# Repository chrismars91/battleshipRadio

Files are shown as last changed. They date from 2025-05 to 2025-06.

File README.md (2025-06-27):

https://www.instructables.com/BattLedRadio-the-LED-Radio-Battleship-SAMD21-Editi/


*** New board gerber below with better JTAG programming pads and a battery powered option. Updated BOM in the link. ***
https://www.pcbway.com/project/shareproject/rfm69_battleship_battery_7544f334.html

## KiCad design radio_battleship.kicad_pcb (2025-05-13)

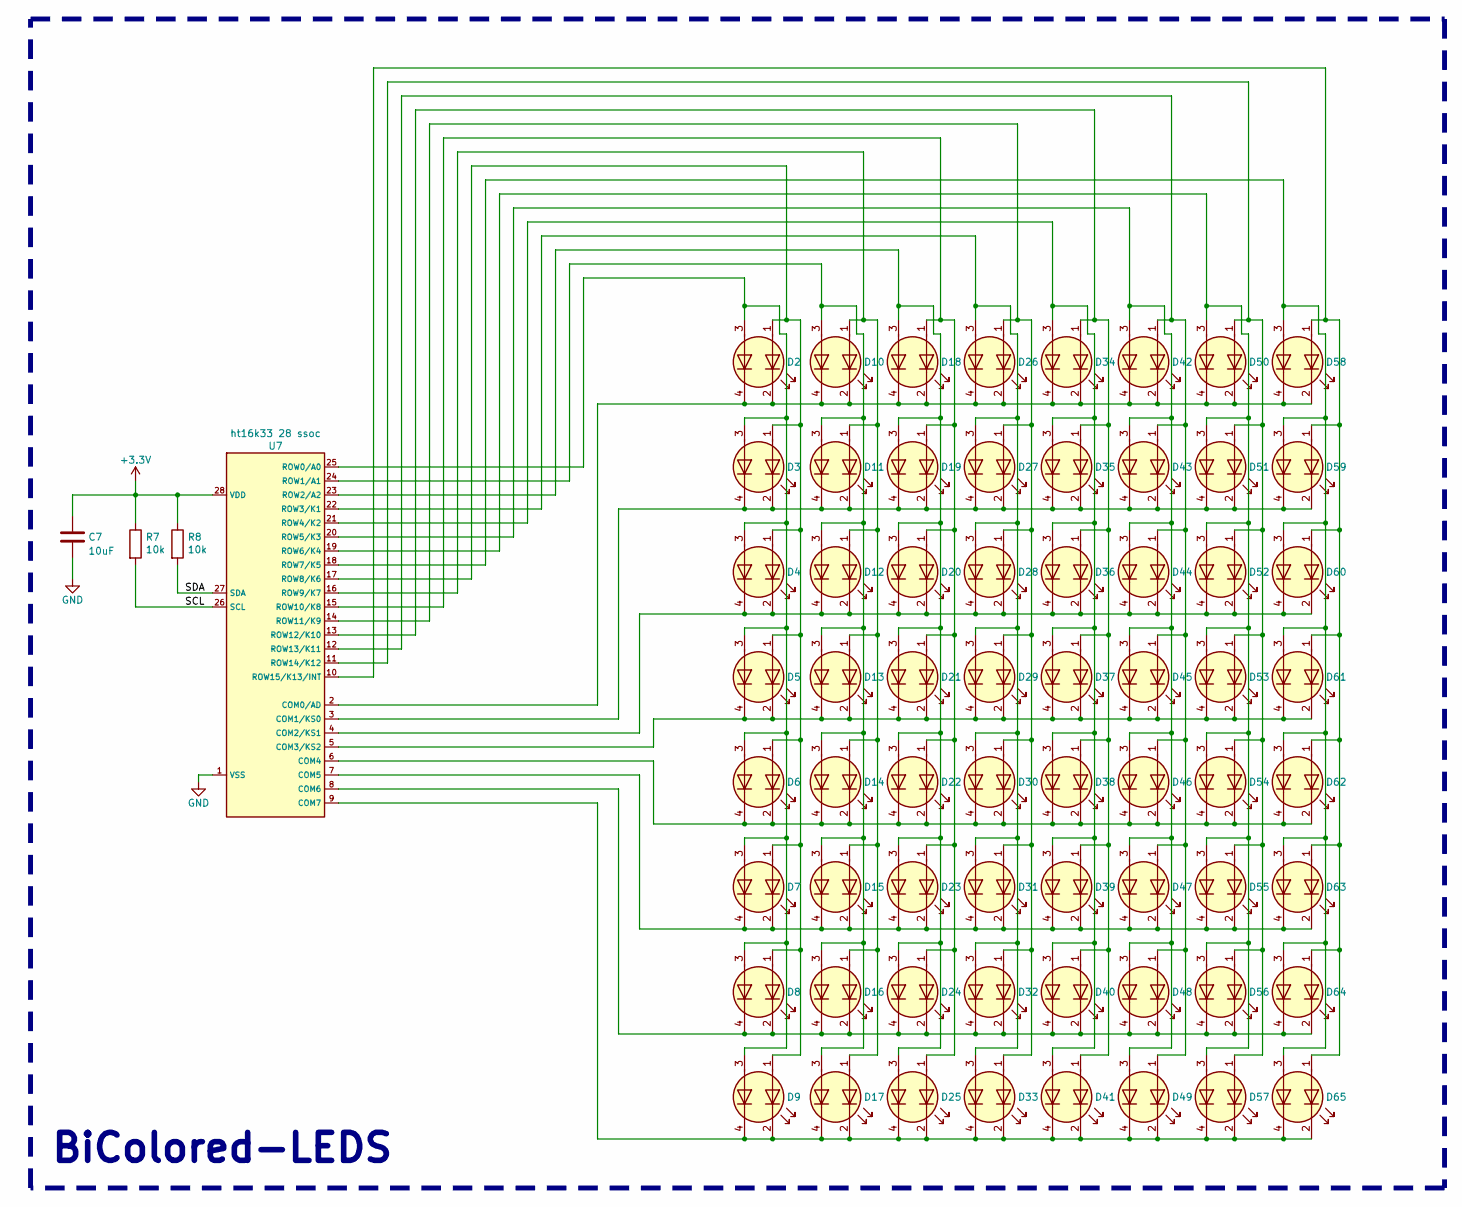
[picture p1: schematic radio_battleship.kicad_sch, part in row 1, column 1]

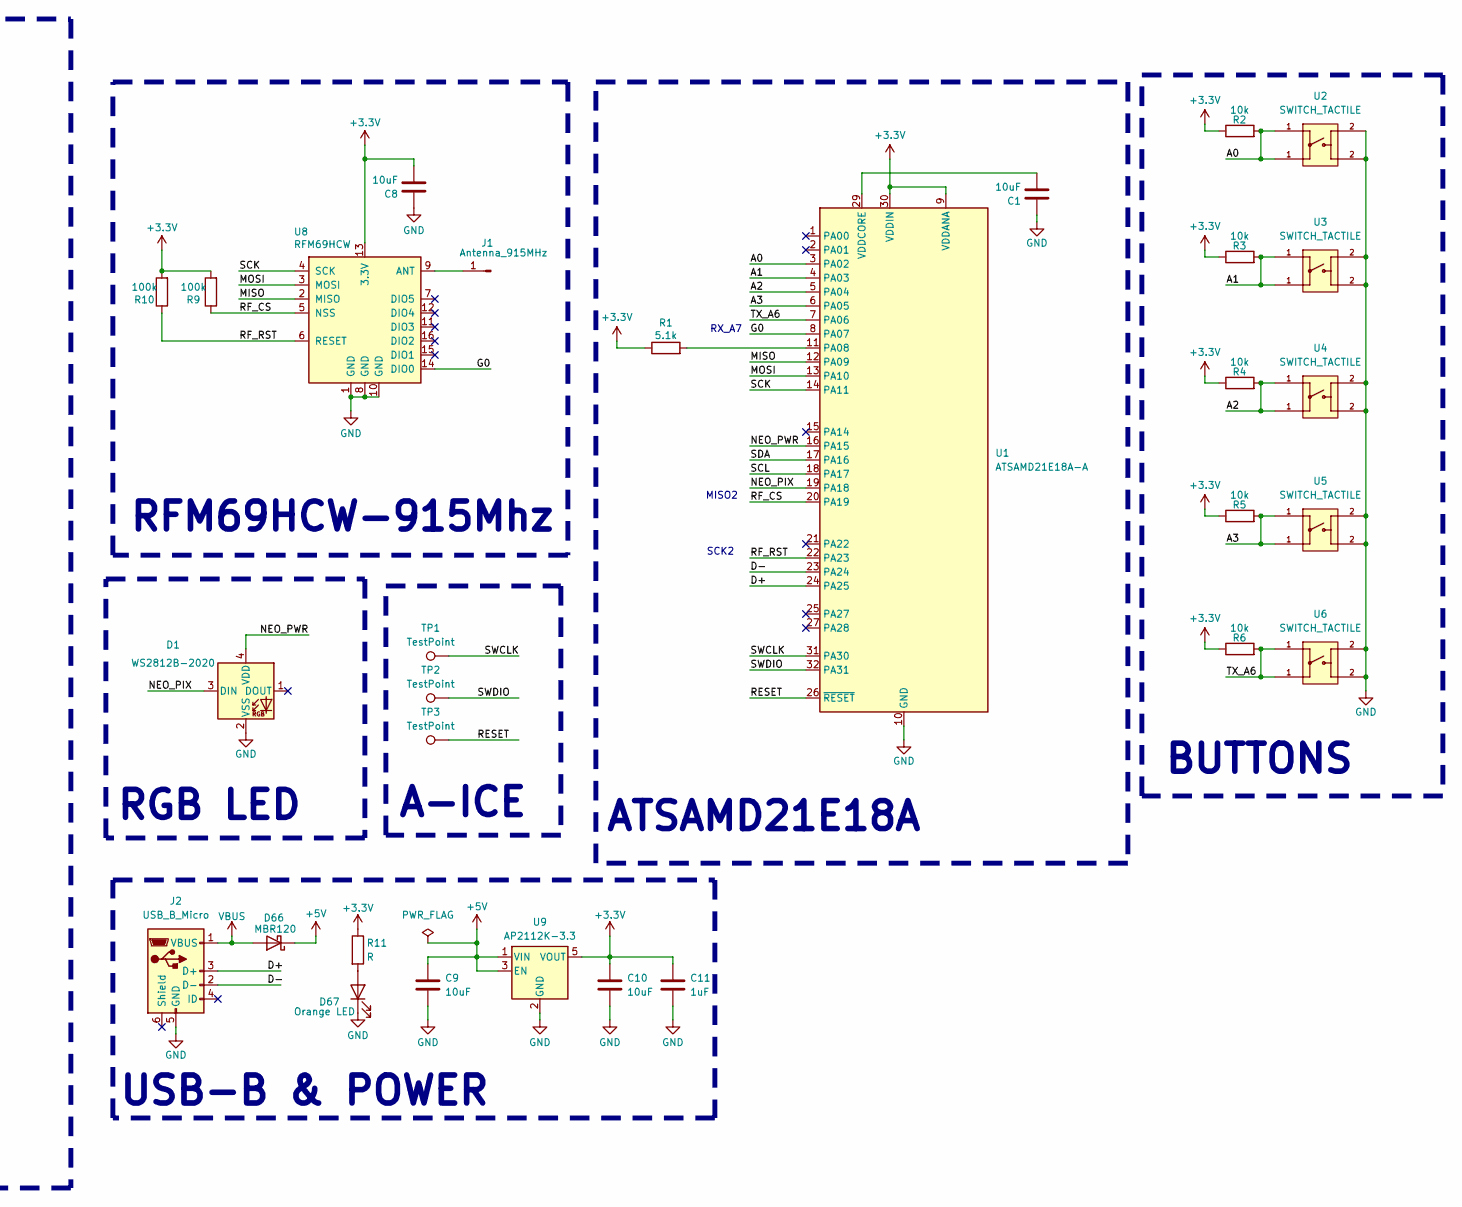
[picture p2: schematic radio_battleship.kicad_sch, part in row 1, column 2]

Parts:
C1, C7, C8, C9, C10: 10uF; C_0603_1608Metric
C11: 1uF; C_0603_1608Metric
D1: WS2812B-2020; custom_ws28_2m_led
D2, D3, D4, D5, D6, D7, D8, D9, D10, D11, D12, D13, D14, D15, D16, D17, D18, D19, D20, D21, D22, D23, D24, D25, D26, D27, D28, D29, D30, D31, D32, D33, D34, D35, D36, D37, D38, D39, D40, D41, D42, D43, D44, D45, D46, D47, D48, D49, D50, D51, D52, D53, D54, D55, D56, D57, D58, D59, D60, D61, D62, D63, D64, D65: LTST-BILED-15X16
D66: MBR120; D_SOD-123F
D67: Orange LED; LED_0805_2012Metric
J1: Antenna_915MHz; ant
J2: USB_B_Micro; USB_Micro-B_Wuerth_629105150521
R1: 5.1k; R_0603_1608Metric
R2, R3, R4, R5, R6, R7, R8: 10k; R_0603_1608Metric
R9, R10: 100k; R_0603_1608Metric
R11: R; R_0603_1608Metric
TP1, TP2, TP3: TestPoint; TestPoint_Pad_2.5x2.5mm
U1: ATSAMD21E18A-A; TQFP-32_7x7mm_P0.8mm
U2, U3, U4, U5, U6: SWITCH_TACTILE
U7: ht16k33 28 ssoc; HT16K33_ssop
U8: RFM69HCW
U9: AP2112K-3.3; SOT-23-5

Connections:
+3.3V: C7.1, C8.2, C10.1, C11.1, R1.1, R2.1, R3.1, R4.1, R5.1, R6.1, R7.1, R8.1, R9.2, R10.2, R11.1, U1.9 (VDDANA), U1.30 (VDDIN), U7.28 (VDD), U8.13 (3.3V), U9.5 (VOUT)
+5V: C9.1, D66.1 (K), U9.1 (VIN), U9.3 (EN)
/A0: R2.2, U1.3 (PA02), U2.1
/A1: R3.2, U1.4 (PA03), U3.1
/A2: R4.2, U1.5 (PA04), U4.1
/A3: R5.2, U1.6 (PA05), U5.1
/D+: J2.3 (D+), U1.24 (PA25)
/D-: J2.2 (D-), U1.23 (PA24)
/G0: U1.8 (PA07), U8.14 (DIO0)
/MISO: U1.12 (PA09), U8.2 (MISO)
/MOSI: U1.13 (PA10), U8.3 (MOSI)
/NEO_PIX: D1.3 (DIN), U1.19 (PA18)
/NEO_PWR: D1.4 (VDD), U1.16 (PA15)
/RESET: TP3.1, U1.26 (~RESET)
/RF_CS: R9.1, U1.20 (PA19), U8.5 (NSS)
/RF_RST: R10.1, U1.22 (PA23), U8.6 (RESET)
/SCK: U1.14 (PA11), U8.4 (SCK)
/SCL: R7.2, U1.18 (PA17), U7.26 (SCL)
/SDA: R8.2, U1.17 (PA16), U7.27 (SDA)
/SWCLK: TP1.1, U1.31 (PA30)
/SWDIO: TP2.1, U1.32 (PA31)
/TX_A6: R6.2, U1.7 (PA06), U6.1
GND: C1.1, C7.2, C8.1, C9.2, C10.2, C11.2, D1.2 (VSS), D67.1 (K), J2.5 (GND), U1.10 (GND), U1.28 (GND), U2.2, U3.2, U4.2, U5.2, U6.2, U7.1 (VSS), U8.1 (GND), U8.8 (GND), U8.10 (GND), U9.2 (GND)
unnamed: D2.1 (A1), D3.1 (A1), D4.1 (A1), D5.1 (A1), D6.1 (A1), D7.1 (A1), D8.1 (A1), D9.1 (A1), U7.17 (ROW8/K6)
unnamed: D2.3 (A2), D3.3 (A2), D4.3 (A2), D5.3 (A2), D6.3 (A2), D7.3 (A2), D8.3 (A2), D9.3 (A2), U7.25 (ROW0/A0)
unnamed: D10.1 (A1), D11.1 (A1), D12.1 (A1), D13.1 (A1), D14.1 (A1), D15.1 (A1), D16.1 (A1), D17.1 (A1), U7.16 (ROW9/K7)
unnamed: D10.3 (A2), D11.3 (A2), D12.3 (A2), D13.3 (A2), D14.3 (A2), D15.3 (A2), D16.3 (A2), D17.3 (A2), U7.24 (ROW1/A1)
unnamed: D2.2 (K1), D2.4 (K2), D10.2 (K1), D10.4 (K2), D18.2 (K1), D18.4 (K2), D26.2 (K1), D26.4 (K2), D34.2 (K1), D34.4 (K2), D42.2 (K1), D42.4 (K2), D50.2 (K1), D50.4 (K2), D58.2 (K1), D58.4 (K2), U7.2 (COM0/AD)
unnamed: D3.2 (K1), D3.4 (K2), D11.2 (K1), D11.4 (K2), D19.2 (K1), D19.4 (K2), D27.2 (K1), D27.4 (K2), D35.2 (K1), D35.4 (K2), D43.2 (K1), D43.4 (K2), D51.2 (K1), D51.4 (K2), D59.2 (K1), D59.4 (K2), U7.3 (COM1/KS0)
unnamed: D4.2 (K1), D4.4 (K2), D12.2 (K1), D12.4 (K2), D20.2 (K1), D20.4 (K2), D28.2 (K1), D28.4 (K2), D36.2 (K1), D36.4 (K2), D44.2 (K1), D44.4 (K2), D52.2 (K1), D52.4 (K2), D60.2 (K1), D60.4 (K2), U7.4 (COM2/KS1)
unnamed: D5.2 (K1), D5.4 (K2), D13.2 (K1), D13.4 (K2), D21.2 (K1), D21.4 (K2), D29.2 (K1), D29.4 (K2), D37.2 (K1), D37.4 (K2), D45.2 (K1), D45.4 (K2), D53.2 (K1), D53.4 (K2), D61.2 (K1), D61.4 (K2), U7.5 (COM3/KS2)
unnamed: D6.2 (K1), D6.4 (K2), D14.2 (K1), D14.4 (K2), D22.2 (K1), D22.4 (K2), D30.2 (K1), D30.4 (K2), D38.2 (K1), D38.4 (K2), D46.2 (K1), D46.4 (K2), D54.2 (K1), D54.4 (K2), D62.2 (K1), D62.4 (K2), U7.6 (COM4)
unnamed: D7.2 (K1), D7.4 (K2), D15.2 (K1), D15.4 (K2), D23.2 (K1), D23.4 (K2), D31.2 (K1), D31.4 (K2), D39.2 (K1), D39.4 (K2), D47.2 (K1), D47.4 (K2), D55.2 (K1), D55.4 (K2), D63.2 (K1), D63.4 (K2), U7.7 (COM5)
unnamed: D8.2 (K1), D8.4 (K2), D16.2 (K1), D16.4 (K2), D24.2 (K1), D24.4 (K2), D32.2 (K1), D32.4 (K2), D40.2 (K1), D40.4 (K2), D48.2 (K1), D48.4 (K2), D56.2 (K1), D56.4 (K2), D64.2 (K1), D64.4 (K2), U7.8 (COM6)
unnamed: D9.2 (K1), D9.4 (K2), D17.2 (K1), D17.4 (K2), D25.2 (K1), D25.4 (K2), D33.2 (K1), D33.4 (K2), D41.2 (K1), D41.4 (K2), D49.2 (K1), D49.4 (K2), D57.2 (K1), D57.4 (K2), D65.2 (K1), D65.4 (K2), U7.9 (COM7)
unnamed: D18.1 (A1), D19.1 (A1), D20.1 (A1), D21.1 (A1), D22.1 (A1), D23.1 (A1), D24.1 (A1), D25.1 (A1), U7.15 (ROW10/K8)
unnamed: D18.3 (A2), D19.3 (A2), D20.3 (A2), D21.3 (A2), D22.3 (A2), D23.3 (A2), D24.3 (A2), D25.3 (A2), U7.23 (ROW2/A2)
unnamed: D26.1 (A1), D27.1 (A1), D28.1 (A1), D29.1 (A1), D30.1 (A1), D31.1 (A1), D32.1 (A1), D33.1 (A1), U7.14 (ROW11/K9)
unnamed: D26.3 (A2), D27.3 (A2), D28.3 (A2), D29.3 (A2), D30.3 (A2), D31.3 (A2), D32.3 (A2), D33.3 (A2), U7.22 (ROW3/K1)
unnamed: D34.1 (A1), D35.1 (A1), D36.1 (A1), D37.1 (A1), D38.1 (A1), D39.1 (A1), D40.1 (A1), D41.1 (A1), U7.13 (ROW12/K10)
unnamed: D34.3 (A2), D35.3 (A2), D36.3 (A2), D37.3 (A2), D38.3 (A2), D39.3 (A2), D40.3 (A2), D41.3 (A2), U7.21 (ROW4/K2)
unnamed: D42.1 (A1), D43.1 (A1), D44.1 (A1), D45.1 (A1), D46.1 (A1), D47.1 (A1), D48.1 (A1), D49.1 (A1), U7.12 (ROW13/K11)
unnamed: D42.3 (A2), D43.3 (A2), D44.3 (A2), D45.3 (A2), D46.3 (A2), D47.3 (A2), D48.3 (A2), D49.3 (A2), U7.20 (ROW5/K3)
unnamed: D50.1 (A1), D51.1 (A1), D52.1 (A1), D53.1 (A1), D54.1 (A1), D55.1 (A1), D56.1 (A1), D57.1 (A1), U7.11 (ROW14/K12)
unnamed: D50.3 (A2), D51.3 (A2), D52.3 (A2), D53.3 (A2), D54.3 (A2), D55.3 (A2), D56.3 (A2), D57.3 (A2), U7.19 (ROW6/K4)
unnamed: D58.1 (A1), D59.1 (A1), D60.1 (A1), D61.1 (A1), D62.1 (A1), D63.1 (A1), D64.1 (A1), D65.1 (A1), U7.10 (ROW15/K13/INT)
unnamed: D58.3 (A2), D59.3 (A2), D60.3 (A2), D61.3 (A2), D62.3 (A2), D63.3 (A2), D64.3 (A2), D65.3 (A2), U7.18 (ROW7/K5)
unnamed: D67.2 (A), R11.2
unnamed: J1.1, U8.9 (ANT)
unnamed: R1.2, U1.11 (PA08)
unnamed: C1.2, U1.29 (VDDCORE)
VBUS: D66.2 (A), J2.1 (VBUS)

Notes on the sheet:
ATSAMD21E18A
RX_A7
RGB LED
MISO2
USB-B & POWER
SCK2
BiColored-LEDS
BUTTONS
A-ICE
RFM69HCW-915Mhz

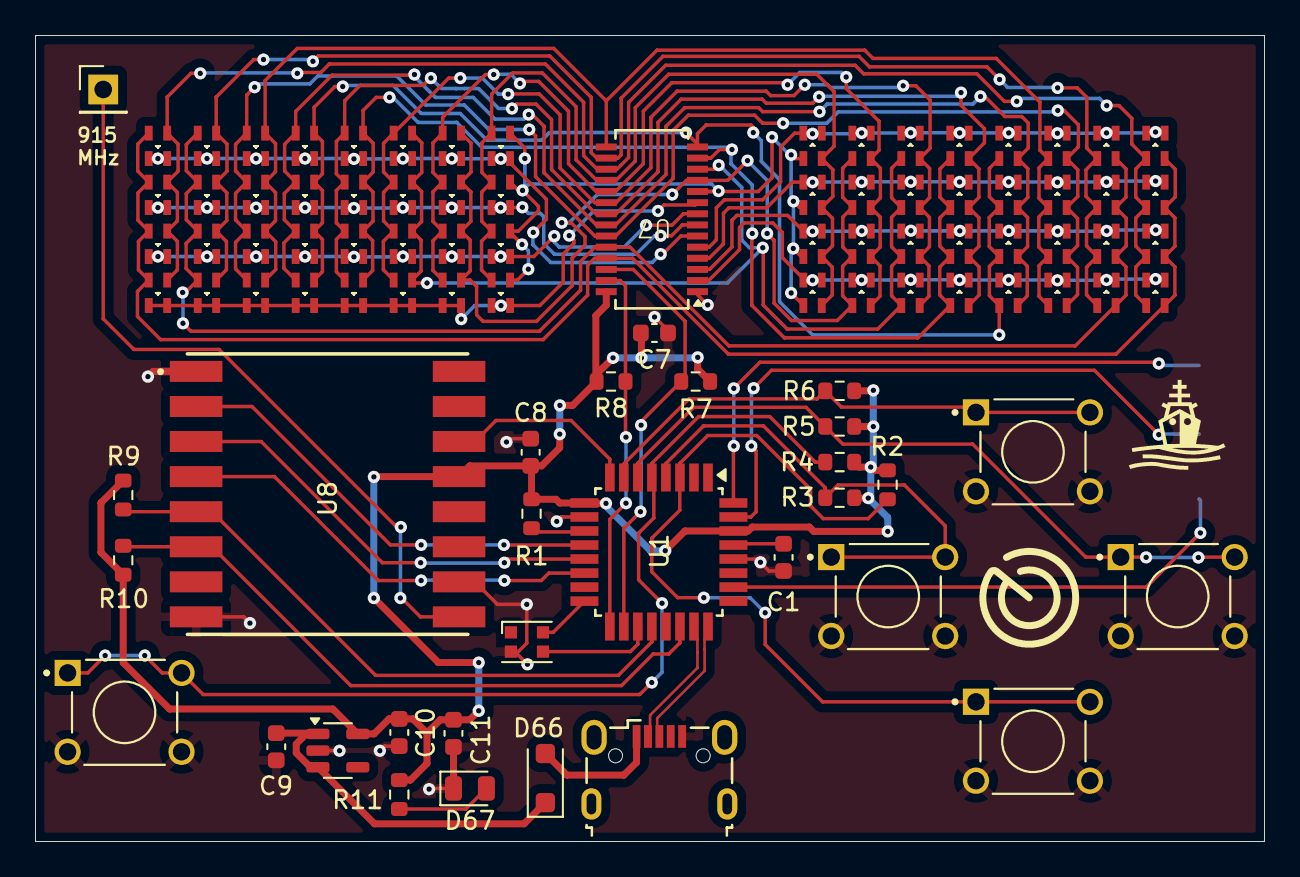
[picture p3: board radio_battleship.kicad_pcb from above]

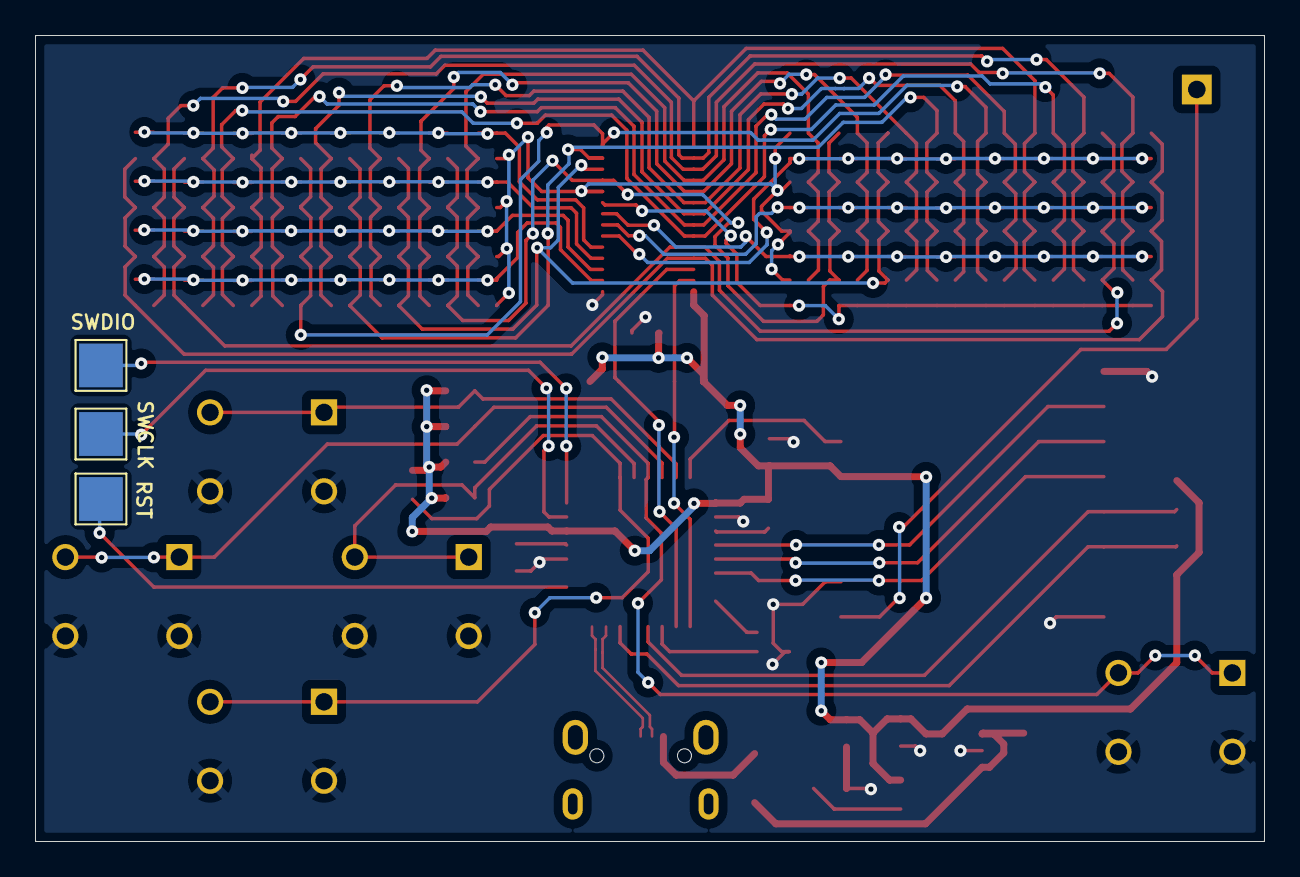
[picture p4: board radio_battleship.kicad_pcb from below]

Board: 2 copper layers, 70.1 x 46.0 mm, 98 parts (3 on the bottom side), 52 nets.
